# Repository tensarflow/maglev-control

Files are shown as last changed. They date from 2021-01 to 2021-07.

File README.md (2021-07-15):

# maglev-control
https://www.youtube.com/watch?v=BNwl1OiK4gQ&feature=youtu.be
<p align="center">
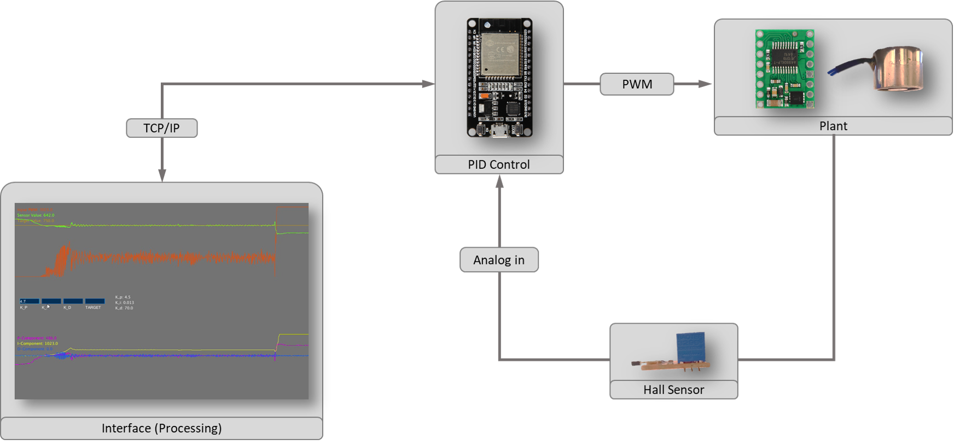
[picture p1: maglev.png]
  
</p>
1. Load the .ino file on the NodeMCUv3 and run it. 
2. Connect the PC to the WiFi Access Point "ESPsoftAP_01" of the NodeMCU with the password "pass-to-soft-AP".
3. Run the .pde file.

To tune the PID Parameters you can use the serial monitor of Arduino IDE:

- P: Increase P-Gain
- p: Decrease P-Gain
- I: Increase I-Gain
- i: Decrease I-Gain
- D: Increase D-Gain
- d: Decrease D-Gain

Setting new PID parameters through the interface is currently causing the a delay in the control loop, which is long enough to let the magnet fall down. (TODO)

## Set up the electronics:

<p align="center">
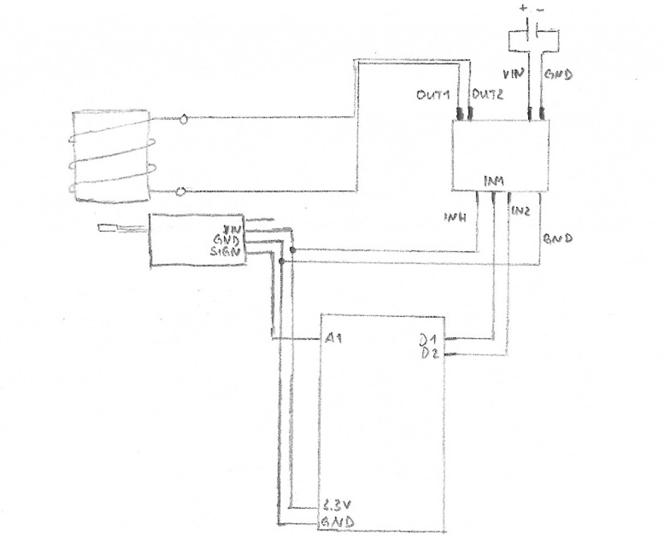
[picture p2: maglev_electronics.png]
  
</p>

## Set Up Software

## To Do:
- Make instruction for software setup

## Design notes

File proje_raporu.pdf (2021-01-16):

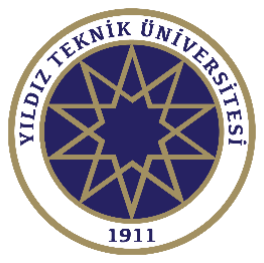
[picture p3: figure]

# Proje Raporu

### Hall Sensörü ile Maglev Sistemi Kontrolcüsü ve Arayüz Geliştirilmesi

Tayyip Ensar Özkaya ⋅ İstanbul 2021

2

### İçindekiler

1 | Giriş ve Problem Tanımı | 3
2 | Çözüm Önerisi ve Hipotez | 3
3 | Yöntem ve Materyaller | 4
4 | Sonuç | 7

3

## 1 Giriş ve Problem Tanımı

“Magnetic” ve “Levitation” kelimelerinin birleşiminden oluşan Maglev kavramı manyetik kuv-

vetle bir cismi havada tutma anlamına geliyor. Genellikle bir elektromıknatıs ve bir ferroman-

yetik cisimden meydana gelen bu dinamik ve kontrolcüsü olduğunda kararsız olan sistemin

kontrolü elektromıknatısın gücünü cismin bu elektromıknatısa olan mesafesine göre ayarlan-

masıyla kontrol edilir. Ferromanyetik cismin elektromıknatısa olan mesafesi, sabit duran bir

hall sensörü ile gerçekleştirilebilir. Hall sensörü, ferromanyetik cismin manyetik alan gücünü

ölçer ve kontrolcü de bu bilgiyi ferromanyetik cismin pozisyonu ile orantılar. Böylelikle kont-

rolcü elektromıknatıs sayesinde cismin pozisyonunu etkiler ve hall sensörü sayesinde etkisini

ölçerek geri bildirim döngüsünü tamamlamış olur. Projenin problem tanımı ise bu sistemin

kontrolcüsünün tasarlanması ve kullanımını kolaylaştıran bir arayüzün geliştirilmesidir. Ayrıca

hall sensörün doğru kullanımı gösterilmiştir.

## 2 Çözüm Önerisi ve Hipotez

Giriş bölümünde tanımlanan problemin çözümü için sekil 1’deki sistem önerilmektedir. Siste-

min kontrolcüsü bir mikroişlemcide programlanmıştır. Bir motor sürücüsü sayesinde kontrol

edilen elektromıknatıs ferromanyetik cisme manyetik alan uygulayarak bir çekme kuvveti oluş-

turur. Cismin elektromıknatısa olan mesafesi ise elektromıknatısın tam altına yerleştirilmiş bir

hall sensörü ile ölçülmektedir. Böylelikle kapalı bir kontrol döngüsü oluşturulmuştur. PID yön-

temiyle kontrol edilen bu sistemin parametrelerini daha kolay ayarlayabilmek için Processing

yazılım ortamında bir arayüz geliştirilmiştir. Bu arayüz üzerinden PID parametreleri ve kazanç-

ları olmak üzere sistemin genel durumunu ve sensör verilerinin de gerçek zamanlı olarak deği-

şimleri izlenebilmektedir.

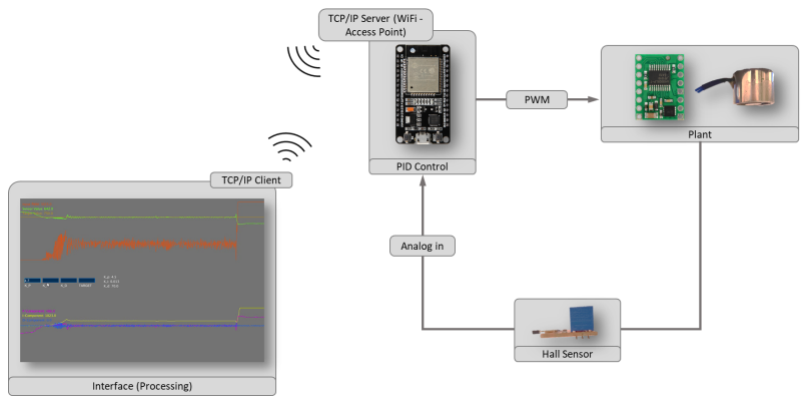
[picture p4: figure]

Şekil 1

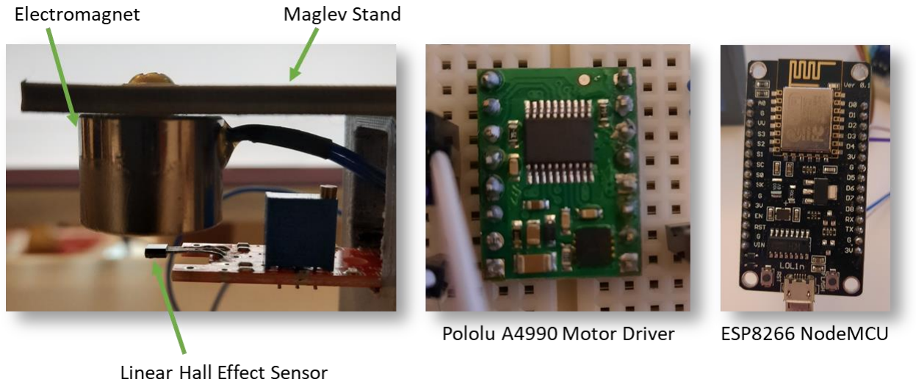
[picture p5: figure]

4

## 3 Yöntem ve Materyaller

Bir önceki bölümde önerilen çözümün gerçekleştirilebilmesi için şekil 2’de gösterilen malze-

meler kullanılmışı. Burada bir adet Pololu A4990 motor sürücü, bir adet ESP8266 NodeMCU,

bir adet lineer hall sensörü, bir adet 12V 2.5N’luk elektromıknatısı ve üç boyutlu yazıcı ile

üretilen bir adet tutucu kullanılmıştır. Pololu A4990 motor sürücüsü düşük voltajlardaki sergi-

lediği performansından dolayı seçilirken ESP8266 NodeMCU mikroişlemci sunduğu wifi ko-

münikasyon olanağı ve yine düşük voltaj ile çalışma kabiliyetiyle öne çıkarak sistem için seçil-

miştir. Ferromanyetik cisim olarak iki adet 3mm’lik neodim mıknatısı kullanılmıştır.

Şekil 2

Sistemin elektronik olarak implementasyonu ise şekil 3’te gösterilmiştir. Harici 12V enerji kay-

nağı ile beslenen sürücü bu enerjiyi elektromıknatısa mikroişlemci tarafından aldığı PWM sin-

yallerine göre aktarır. Mikroişlemci ise USB OTG girişi üzerinden 5V ile beslenmektedir.

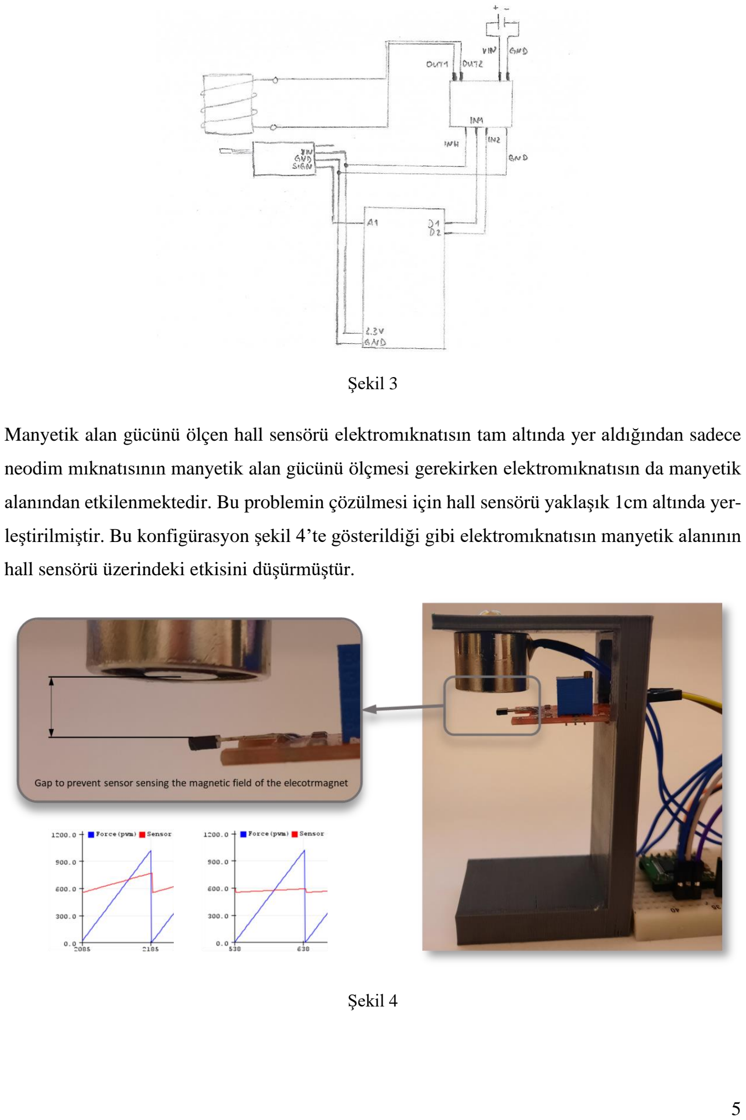
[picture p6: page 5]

5

Şekil 3

Manyetik alan gücünü ölçen hall sensörü elektromıknatısın tam altında yer aldığından sadece

neodim mıknatısının manyetik alan gücünü ölçmesi gerekirken elektromıknatısın da manyetik

alanından etkilenmektedir. Bu problemin çözülmesi için hall sensörü yaklaşık 1cm altında yer-

leştirilmiştir. Bu konfigürasyon şekil 4’te gösterildiği gibi elektromıknatısın manyetik alanının

hall sensörü üzerindeki etkisini düşürmüştür.

Şekil 4

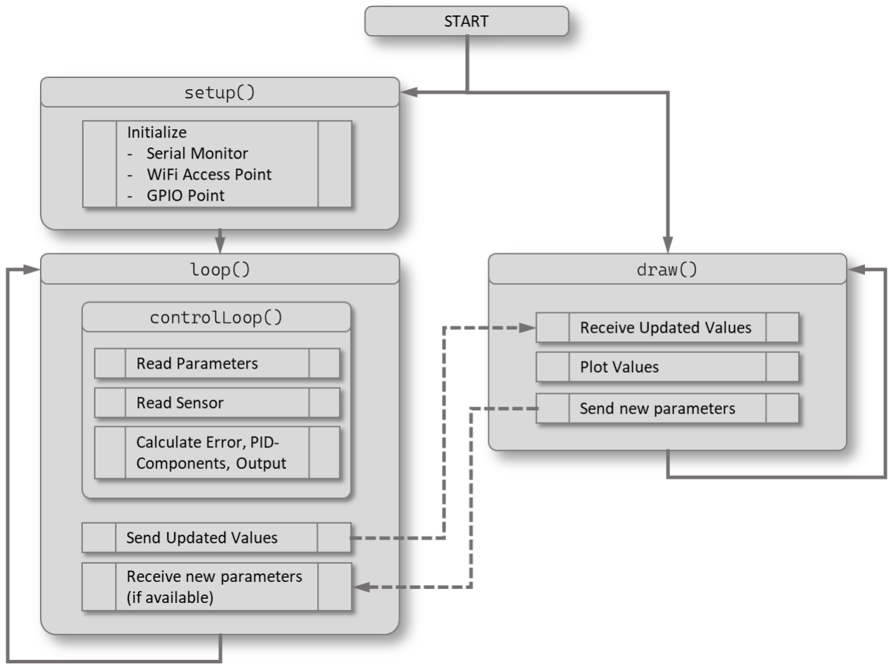
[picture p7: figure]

6

ESP8266 NodeMCU üzerinde Arduino IDE ile ve bir Windows PC ile Processing IDE geliş-

tirilmiş yazılımın genel şeması şekil 5’te gösterilmektedir. Hem arayüz hem de NodeMCU üze-

rindeki yazılımlar çalıştırıldığında ilk olarak mikroişlemci üzerindeki iletişim kanalları ve

GPIO pinleri tanımlanmaktadır. Ardından Mikroişlemci üzerinde kontrol döngüsüne girilerek

PID parametreleri okunur, ardından hall sensöründen güncel veri okunur ve bu verilere daya-

narak motor sürücüsüne gönderilecek sinyal PID algoritmasıyla hesaplanır ve motor sürücü-

süne gönderilir. Bu işlem gerçekleştirildikten sonra sensör verisi, motora gönderilen PWM de-

ğeri ve PID parametreleri socket iletişimi ile wifi üzerinden arayüze gönderilmektedir. Arayüz-

deki döngüde ise bu veriler okunur, grafiklerde güncellenir ve yeni verilerin gelmesi beklenir.

Eğer kullanıcı PID parametrelerini değiştirdiyse yeni verilerin gelmesi beklenmeden önce bu

veriler mikroişlemciye gönderilir ve orada güncellenir. Mikroişlemci ve bilgisayar arasındaki

Wifi bağlantısı, mikroişlemci üzerinde acılan Access Point üzerinden gerçekleştirilir. Böyle-

likle mikroişlemcinin gömülü yazılımı belirli bir ağa bağlı kalmadan her yerde kullanılabilir.

Şekil 5

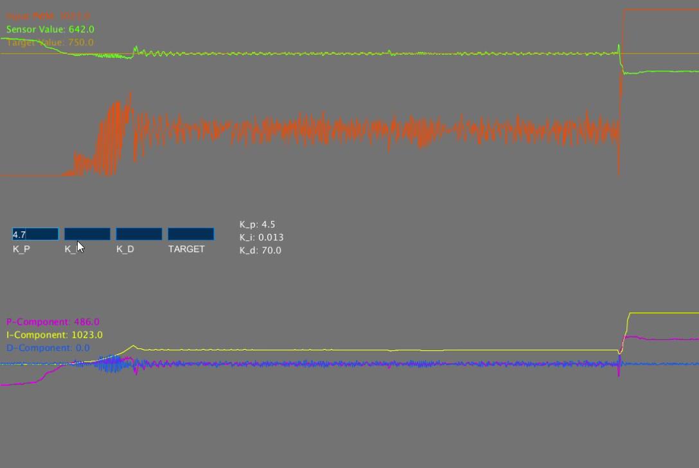
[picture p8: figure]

7

## 4 Sonuç

Şekil 6’da elde edilen sonuçlar arayüz üzerinden gösterilmektedir. Deneyerek elde edilen PID değerleri şekilde göründüğü gibi kontrolcü ile sistemi kararlı hale getirmektedir. Ölçülen veri-

lere göre sistemin kararlı hale getirilmesi yaklaşık olarak 2,5 saniye sürmektedir.

Şekil 6

Bu sistemin daha performanslı ve stabil çalışması için gömülü yazılıma verilerin taşındığı kısmı

threading fonksiyonları olarak implemente edilebilir. Böylelikle iletişim hızı sistemin perfor-

mansını etkilemez ve kontrol algoritması gerçek zamanda çalışabilir.

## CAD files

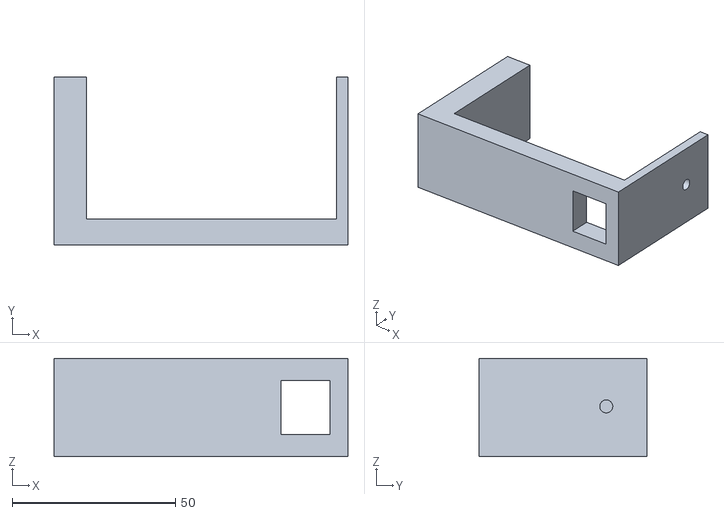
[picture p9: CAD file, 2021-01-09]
maglev_stand.stl
90.0 x 51.5 x 30.0

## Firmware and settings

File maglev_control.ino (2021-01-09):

#include <ESP8266WiFi.h>

// Pins
int hallSensorPin = A0;
uint8_t M1DIR = D1;
uint8_t M1PWM = D2;

// PID Variables
int force = 0;
int hallSensorVal;
int setValue = 750;
double K_p = 9.4 / 2.0;
double K_i = 19.8 / 2.0;
double K_d = 0.05 / 0.2;
double P = 0;
double I = 0;
double D = 0;
unsigned long t_prev = 0;
unsigned long t_curr = 0;
double dt = 0;
int e_prev = 0;
int e_curr = 0;
double de = 0;

void setup()
{
    Serial.begin(115200);
    Serial.println();

    /*Serial.print("Setting soft-AP ... ");
  Serial.println(WiFi.softAP("ESPsoftAP_01", "pass-to-soft-AP") ? "Ready" : "Failed!");
  Serial.println(WiFi.localIP());*/

    analogWriteFreq(20000);

    pinMode(hallSensorPin, INPUT);
    pinMode(M1DIR, OUTPUT);
    pinMode(M1PWM, OUTPUT);
    digitalWrite(M1DIR, LOW);
    digitalWrite(M1PWM, LOW);
}

void loop()
{

    // Get Feedback
    hallSensorVal = analogRead(hallSensorPin);

    t_prev = t_curr;
    t_curr = millis();
    dt = t_curr - t_prev;
    if (dt <= 0)
        return;

    e_prev = e_curr;
    e_curr = setValue - hallSensorVal;
    de = e_curr - e_prev;

    P = e_curr * K_p;
    I = I + K_i * e_curr * dt;
    D = K_d * de / dt;

    force = P + I + D;

    // limit values
    if (force >= 1024)force = 1023;
    else if (force <= 0)force = 0;
    if (I >= 1024)I = 1023;
    else if (I <= 0)I = 0;

    eMagnet(HIGH, force);

    //
    Serial.print("Input(pwm):");
    Serial.print(force);
    Serial.print(" Output:");
    Serial.print(hallSensorVal);
    Serial.print(" setValue:");
    Serial.print(setValue);
    Serial.print(" P:");
    Serial.print(P);
    Serial.print(" I:");
    Serial.print(I);
    Serial.print(" D:");
    Serial.print(D);
    Serial.println(" ");

    delay(20);
}

void eMagnet(int polarity, int force)
{
    digitalWrite(M1DIR, polarity);
    analogWrite(M1PWM, force);
}

void serialCommand(char command)
{
    char output[255];

    switch (command)
    {
    case 'P':
        gKp += KP_INCREMENT;
        break;
    case 'p':
        gKp -= KP_INCREMENT;
        if (0 > gKp)
            gKp = 0;
        break;

    case 'D':
        gKd += KD_INCREMENT;
        break;
    case 'd':
        gKd -= KD_INCREMENT;
        if (0 > gKd)
            gKd = 0;
        break;

    case 'I':
        gKi += KI_INCREMENT;
        break;
    case 'i':
        gKi -= KI_INCREMENT;
        if (0 > gKi)
            gKi = 0;
        break;

    case 'T':
        gTargetValue += VALUE_INCREMENT;
        break;
    case 't':
        gTargetValue -= VALUE_INCREMENT;
        if (0 > gTargetValue)
            gTargetValue = 0;
        break;

    //Print current settings. Also printed after any of the above cycles.
    case 'V':
    case 'v':
        break;

    //Ignore unrecognised characters
    default:
        return;
    }

    //Why so complicated? Arduino doesn't include support for %f by default and requires an additional library, so we rip it open manually. Will not support negative numbers or indefinite precision.
    //This one line causes 3026 bytes of ROM to be used, almost half the sketch size...so if you run out of space, disable this (or simplify it).
    sprintf(output, "Target Value: [%3d] Current PWM duty cycle [%3d] Current sensor value [%4d] Kp [%2d.%02d] Kd [%2d.%02d] Ki,Integral Error [.%04d,%d] Idle timeout [%d]\n",
            gTargetValue,
            gCurrentDutyCycle,
            gNextSensorReadout,
            (int)(gKp + 0.0001),
            roundValue(gKp * 100) % 100,
            (int)(gKd + 0.0001),
            roundValue(gKd * 100) % 100,
            roundValue(gKi * 10000) % 10000,
            gIntegralError,
            gIdleTime);

    Serial.print(output);
}

void loop()[

]

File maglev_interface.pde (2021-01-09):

import processing.net.*;
import controlP5.*;


Client client; 
String input;
float buffer[];

int width = 1080;
int factor_1 = 4;
int factor_2 = 13;
int shiftGraph_1 = 450;
int shiftGraph_2 = 160;

ControlP5 cp5;
String[] textfieldNames = {"K_p", "K_i", "K_d", "Target"};

float[] data0 = new float[width]; 
float[] data1 = new float[width]; 
float[] data2 = new float[width];
float[] data3 = new float[width];
float[] data4 = new float[width];
float[] data5 = new float[width];
float[] data6 = new float[width];
float[] data7 = new float[width];
float[] data8 = new float[width];
float newDataPoint0 = 0;   
float newDataPoint1 = 0;                                             
float newDataPoint2 = 0;
float newDataPoint3 = 0;
float newDataPoint4 = 0;
float newDataPoint5 = 0;
float newDataPoint6 = 0;
float newDataPoint7 = 0;
float newDataPoint8 = 0;


void setup() { 
  size(1080,720);
  frameRate(60);
  client = new Client(this, "192.168.4.1", 8888);
  
  
  cp5 = new ControlP5(this);
  PFont font = createFont("arial",14);

  int y = 350;
  int x = 20;
  int spacing = 80;
  for(String name: textfieldNames){
    cp5.addTextfield(name)
       .setPosition(x,y)
       .setSize(70,20)
       .setFont(font)
       .setFocus(true)
       .setColor(color(255,255,255))
       ;
     x += spacing;
  }
} 

void draw() { 
  background(115);
  
  if (client.available() > 0) {
    input = client.readString();
    println(input);
    input = input.substring(0,input.indexOf("\n"));
    buffer = float(split(input, ' '));
    
    // Put texts
    String newDataPointString0 = "Input PWM: " + str(buffer[0]);
    String newDataPointString1 = "Sensor Value: " + str(buffer[1]);
    String newDataPointString2 = "Target Value: " + str(buffer[2]);
    String newDataPointString3 = "K_p: " + str(buffer[3]);
    String newDataPointString4 = "K_i: " + str(buffer[4]);
    String newDataPointString5 = "K_d: " + str(buffer[5]);
    String newDataPointString6 = "P-Component: " + str(buffer[6]);
    String newDataPointString7 = "I-Component: " + str(buffer[7]);
    String newDataPointString8 = "D-Component: " + str(buffer[8]);
    
    textSize(14);
    fill(254, 87, 0);
    text(newDataPointString0, 10, 30);
    fill(87, 255, 0);
    text(newDataPointString1, 10, 50);
    fill(204, 153, 0);
    text(newDataPointString2, 10, 70);
    fill(255);
    text(newDataPointString3, 370, 350);
    fill(255);
    text(newDataPointString4, 370, 370);
    fill(255);
    text(newDataPointString5, 370, 390);
    fill(254, 0, 255);
    text(newDataPointString6, 10, 500);
    fill(254, 255, 0);
    text(newDataPointString7, 10, 520);
    fill(0, 87, 255);
    text(newDataPointString8, 10, 540);
    
    newDataPoint0 = buffer[0] / factor_1 + shiftGraph_1;   
    newDataPoint1 = buffer[1] / factor_1 + shiftGraph_1;                                             
    newDataPoint2 = buffer[2] / factor_1 + shiftGraph_1;
    //newDataPoint3 = buffer[3] / factor;
    //newDataPoint4 = buffer[4] / factor;
    //newDataPoint5 = buffer[5] / factor;
    newDataPoint6 = buffer[6] / factor_2 + shiftGraph_2;
    newDataPoint7 = buffer[7] / factor_2 + shiftGraph_2;
    newDataPoint8 = buffer[8] / factor_2 + shiftGraph_2;
    
    for(int i = 0; i < width-1; i++)                                 //each interation of draw, shift data points one pixel to the left to simulate a continuously moving graph
    {
      data0[i] = data0[i+1];
      data1[i] = data1[i+1];
      data2[i] = data2[i+1];
      //data3[i] = data3[i+1];
      //data4[i] = data4[i+1];
      //data5[i] = data5[i+1];
      data6[i] = data6[i+1];
      data7[i] = data7[i+1];
      data8[i] = data8[i+1];
    }
    
    data0[width-1] = newDataPoint0;                                 //introduce the bufffered data into the rightmost data slot
    data1[width-1] = newDataPoint1;
    data2[width-1] = newDataPoint2;
    //data3[width-1] = newDataPoint3;
    //data4[width-1] = newDataPoint4;
    //data5[width-1] = newDataPoint5;
    data6[width-1] = newDataPoint6;
    data7[width-1] = newDataPoint7;
    data8[width-1] = newDataPoint8;
    
    strokeWeight(1);
    
    pushMatrix();
    translate(0, 720);
    scale(1,-1);
    for(int i = width-1; i > 0; i--)                                
    {
      stroke(254, 87, 0);
      line(i,data0[i-1], i+1, data0[i]);        // force
      stroke(87, 255, 0);
      line(i,data1[i-1], i+1, data1[i]);        // halsensorval
      stroke(204, 153, 0);
      line(i,data2[i-1], i+1, data2[i]);        // targetval
      //stroke(0,0,255);
      //line(i,data3[i-1], i+1, data3[i]);
      //stroke(0,0,255);
      //line(i,data4[i-1], i+1, data4[i]); 
      //stroke(0,0,255);
      //line(i,data5[i-1], i+1, data5[i]); 
      stroke(254, 0, 255);
      line(i,data6[i-1], i+1, data6[i]);        // P
      stroke(254, 255, 0);
      line(i,data7[i-1], i+1, data7[i]);        // I
      stroke(0, 87, 255);
      line(i,data8[i-1], i+1, data8[i]);        // D
    }
    popMatrix();
  } 
}

void controlEvent(ControlEvent theEvent) {
  if(theEvent.isAssignableFrom(Textfield.class)) {
    println("controlEvent: accessing a string from controller '" +theEvent.getName()+"': " +theEvent.getStringValue() );
    client.write(theEvent.getName() + " " + theEvent.getStringValue());
    
  }
}
